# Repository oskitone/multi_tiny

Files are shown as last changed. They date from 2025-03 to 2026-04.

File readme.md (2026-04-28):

# multi_tiny

Thinking about an adapter board to connect multiple ATtiny85s to a single programmer using off-the-shelf DIP parts.

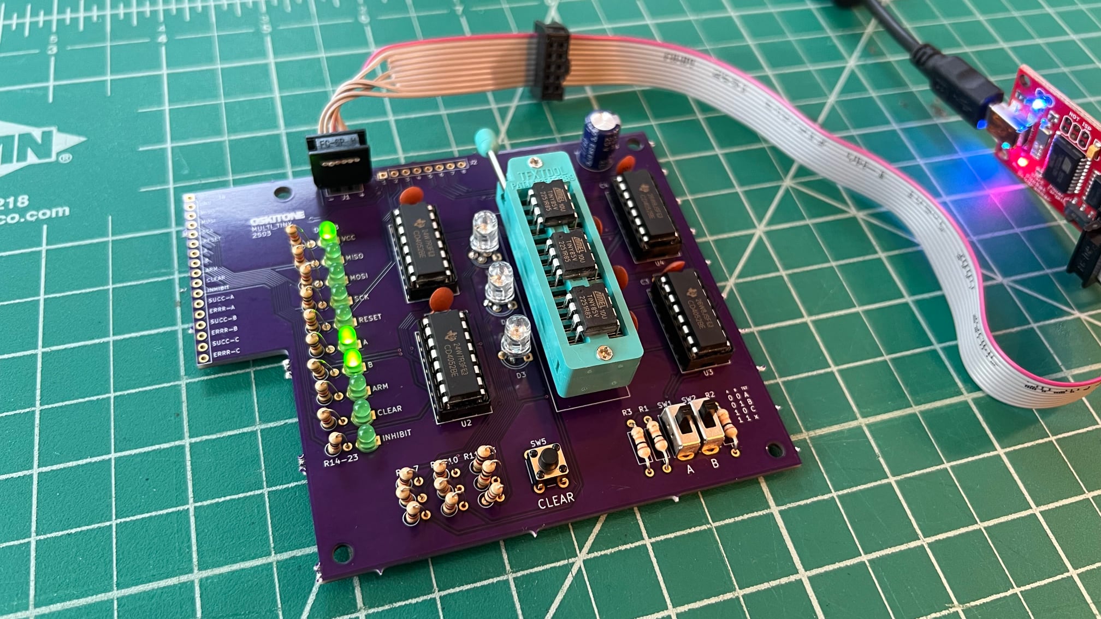
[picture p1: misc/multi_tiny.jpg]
multi_tiny


_Incredibly_ work-in-progress.

## Requirements / Goals

- Long ZIF socket for fast engagement on multiple chips simultaneously
- Programming is done on each chip individually
- Each chip can connect to target PCB for manual testing
- Support for both manual chip and auto/digital chip selection
- Indicators for board/chip-level statuses
- ~Chainable

## PCB TODOs

- Reverse address pin switch order
- Fix ZIF footprint. Component pins are larger than regular DIP socket
- Unused row fixture holes are misplaced
- Maybe rethink IO header position

## Open questions / Down the line / Considerations

- Do I really need four discrete, per-chip pins to program? Sharing common pins and only multiplexing the minimum could simplify BOM.
- Standalone operation w/o a big computer. Raspberry Pi? SD card for storing hex?
- Queue system: load ZIF and mark ready for programming. LEDs indicate when they're ready, and they can be removed while other ZIFs are being used.
- Arbitrary pin routing to support other chips, pin counts, and number of chips per socket
- For now, intentionally not pursuing...
  - Chip switching could be done with manual switches instead of multiplexers. They'd be weird and expensive and obviously not digitally controllable.
  - Programming chips in parallel is feasible (and, anecdotally, commonplace) but require extra verification to test.
  - Could skip multiplexers and instead use multiple sets of GPIO for ICSP pins. It moves a a lot of the complexity into software, which might be nice! Cons: heavily coupled to specific tech, connecting to a target PCB less straightforward.
  - I'm using the 28 pin ZIF because that's what I have for programming the ATmega328. 32 and 40 pin ZIFs have wider pin spacings but, if I'm reading correctly, may still work for DIP8 chipss.

## `DATE REV 2503`

### Schematic

schematic

### BOM

| Designator | Footprint | Quantity | Designation |
| --- | --- | --- | --- |
| C1 to C7 | C_Disc_D5.0mm_W2.5mm_P5.00mm | 7 | .1uF |
| C8 | CP_Radial_D8.0mm_P3.50mm | 1 | 220uF |
| D1 to D3 | LED_D5.0mm-4_RGB_Staggered_Pins | 3 | LED_RKGB |
| D4 to D13  | LED_D3.0mm | 10 | LED |
| J1 | PinHeader_2x03_P2.54mm_Vertical | 1 | Conn_02x03_Odd_Even |
| J2 | PinHeader_1x08_P2.54mm_Vertical | 1 | Conn_01x08 |
| J3 | DIP-28_W7.62mm_LongPads | 1 | 28pin ZIF |
| J4 | PinHeader_1x17_P2.54mm_Vertical | 1 | Conn_01x17 |
| R1 to R3 | R_Axial_DIN0207_L6.3mm_D2.5mm_P10.16mm_Horizontal | 3 | 10k |
| R5 to R23  | R_Axial_DIN0207_L6.3mm_D2.5mm_P2.54mm_Vertical | 19 | 1k |
| SW1, SW2 | SW_Slide_SPDT_Straight_CK_OS102011MS2Q | 2 | SW_SPDT |
| SW4, SW5 | SW_PUSH_6mm | 2 | SW_SPST |
| U1 to U4 | DIP-16_W7.62mm_Socket_LongPads | 4 | CD4052B |

## License

Designed by Oskitone. Please support future projects by purchasing from [Oskitone](https://www.oskitone.com/).

Creative Commons Attribution/Share-Alike, all text above must be included in any redistribution. See license.txt for additional details.

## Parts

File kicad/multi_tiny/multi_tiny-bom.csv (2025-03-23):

Id | Designator | Footprint | Quantity | Designation | Supplier and ref
1 | U4,U2,U1,U3 | DIP-16_W7.62mm_Socket_LongPads | 4 | CD4052B
2 | mouse-bite-1mm-3mm,mouse-bite-1mm-3mm,mouse-bite-1mm-3mm | mouse-bite-1mm-3mm | 3 | VAL**
3 | J1 | PinHeader_2x03_P2.54mm_Vertical | 1 | Conn_02x03_Odd_Even
4 | J3 | DIP-28_W7.62mm_LongPads | 1 | 28pin ZIF
5 | R22,R13,R18,R8,R16,R6,R10,R21,R14,R7,R11,R23,R20,R15,R12,R19,R9,R17,R5 | R_Axial_DIN0207_L6.3mm_D2.5mm_P2.54mm_Vertical | 19 | 1k
6 | D5 | LED_D3.0mm | 1 | MISO
7 | C1,C2,C7,C6,C5,C3,C4 | C_Disc_D5.0mm_W2.5mm_P5.00mm | 7 | .1uF
8 | SW4,SW5 | SW_PUSH_6mm | 2 | SW_SPST
9 | D13 | LED_D3.0mm | 1 | INHIBIT
10 | R3,R2,R1 | R_Axial_DIN0207_L6.3mm_D2.5mm_P10.16mm_Horizontal | 3 | 10k
11 | Ref**,Ref** | branding | 2 | Val**
12 | D9 | LED_D3.0mm | 1 | A
13 | D12 | LED_D3.0mm | 1 | CLEAR
14 | D6 | LED_D3.0mm | 1 | MOSI
15 | J2 | PinHeader_1x08_P2.54mm_Vertical | 1 | Conn_01x08
16 | J4 | PinHeader_1x17_P2.54mm_Vertical | 1 | Conn_01x17
17 | D1,D3,D2 | LED_D5.0mm-4_RGB_Staggered_Pins | 3 | LED_RKGB
18 | SW1,SW2 | SW_Slide_SPDT_Straight_CK_OS102011MS2Q | 2 | SW_SPDT
19 | D4 | LED_D3.0mm | 1 | VCC
20 | D8 | LED_D3.0mm | 1 | RESET
21 | C8 | CP_Radial_D8.0mm_P3.50mm | 1 | 220uF
22 | D7 | LED_D3.0mm | 1 | SCK
23 | D10 | LED_D3.0mm | 1 | B
24 | D11 | LED_D3.0mm | 1 | ARM

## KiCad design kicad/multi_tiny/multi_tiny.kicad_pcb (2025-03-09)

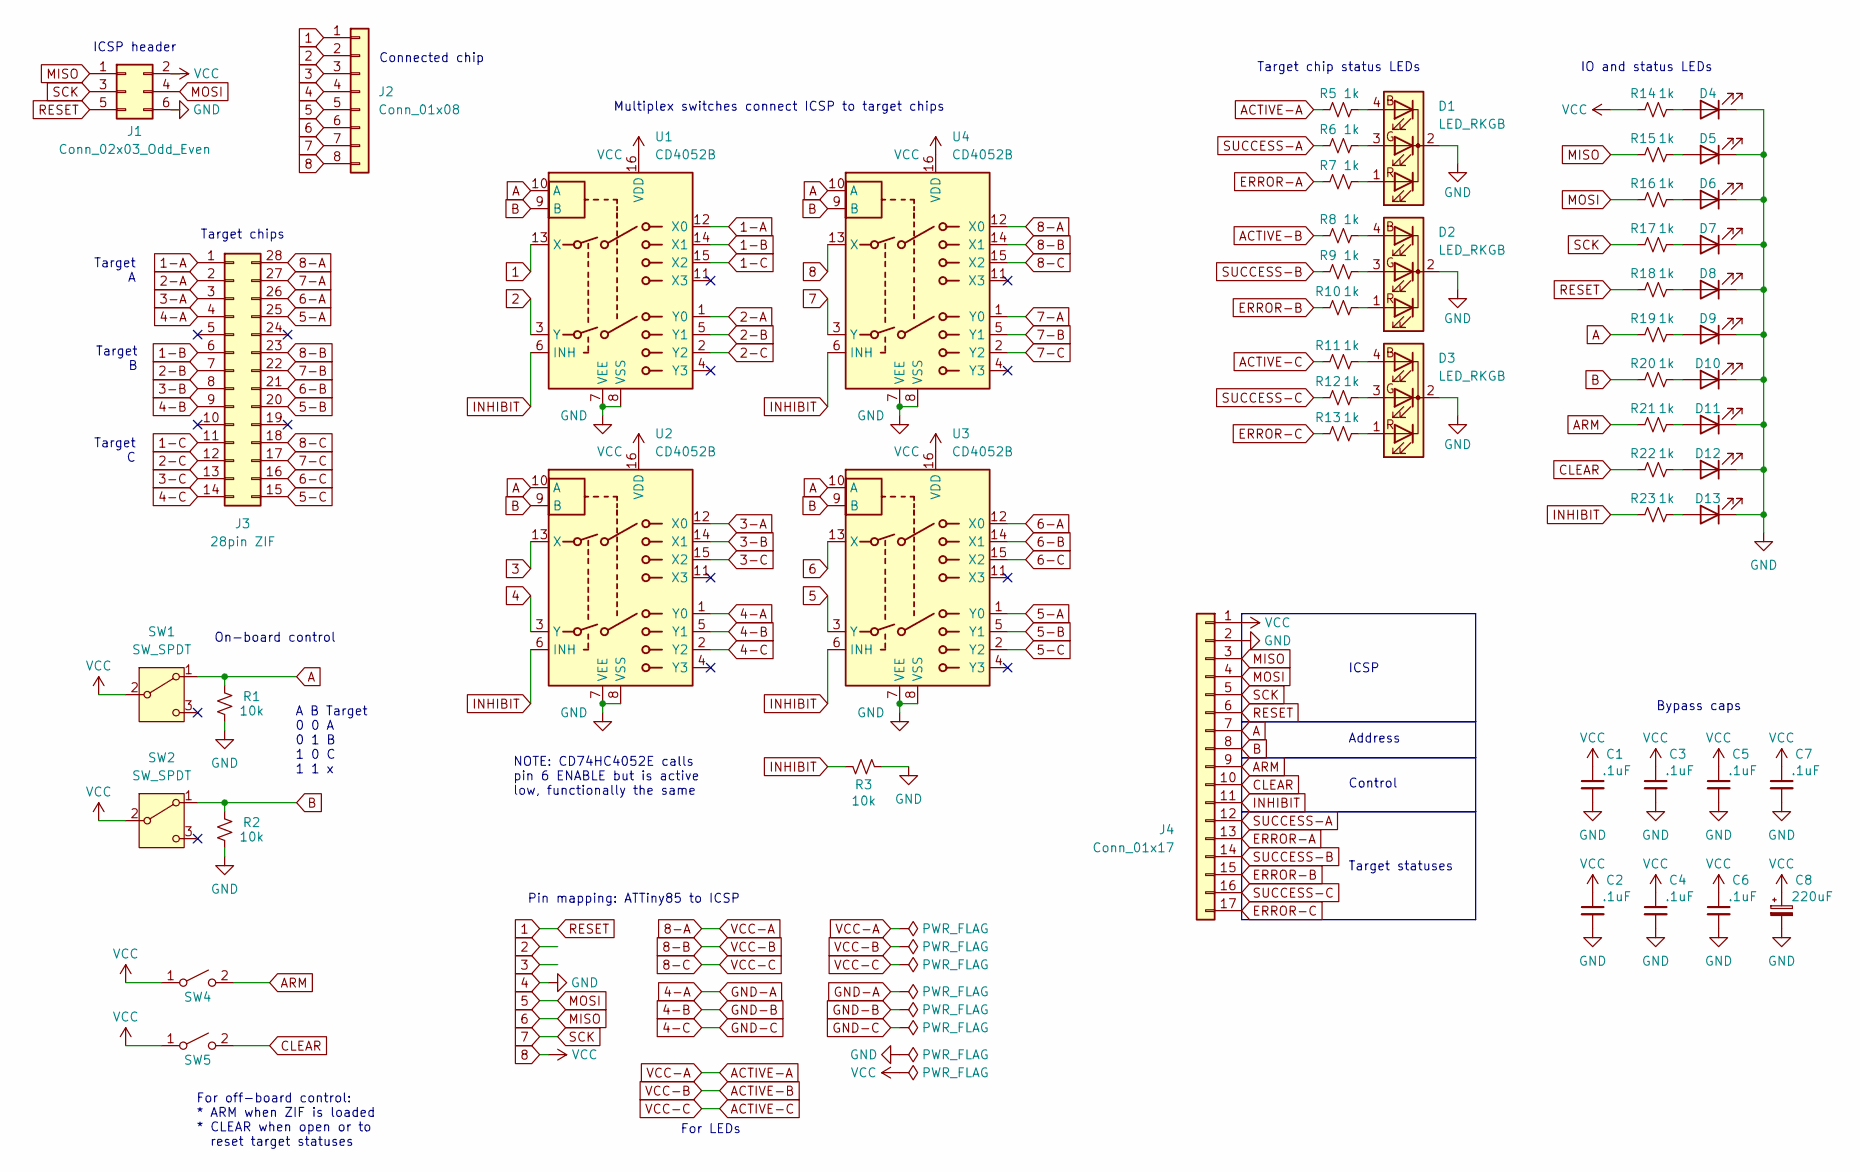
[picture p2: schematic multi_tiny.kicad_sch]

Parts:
C1, C2, C3, C4, C5, C6, C7: .1uF; C_Disc_D5.0mm_W2.5mm_P5.00mm
C8: 220uF; CP_Radial_D8.0mm_P3.50mm
D1, D2, D3: LED_RKGB; LED_D5.0mm-4_RGB_Staggered_Pins
D4: VCC; LED_D3.0mm
D5: MISO; LED_D3.0mm
D6: MOSI; LED_D3.0mm
D7: SCK; LED_D3.0mm
D8: RESET; LED_D3.0mm
D9: A; LED_D3.0mm
D10: B; LED_D3.0mm
D11: ARM; LED_D3.0mm
D12: CLEAR; LED_D3.0mm
D13: INHIBIT; LED_D3.0mm
J1: Conn_02x03_Odd_Even; PinHeader_2x03_P2.54mm_Vertical
J2: Conn_01x08; PinHeader_1x08_P2.54mm_Vertical
J3: 28pin ZIF; DIP-28_W7.62mm_LongPads
J4: Conn_01x17; PinHeader_1x17_P2.54mm_Vertical
R1, R2, R3: 10k; R_Axial_DIN0207_L6.3mm_D2.5mm_P10.16mm_Horizontal
R5, R6, R7, R8, R9, R10, R11, R12, R13, R14, R15, R16, R17, R18, R19, R20, R21, R22, R23: 1k; R_Axial_DIN0207_L6.3mm_D2.5mm_P2.54mm_Vertical
SW1, SW2: SW_SPDT; SW_Slide_SPDT_Straight_CK_OS102011MS2Q
SW4, SW5: SW_SPST; SW_PUSH_6mm
U1, U2, U3, U4: CD4052B; DIP-16_W7.62mm_Socket_LongPads

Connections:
1: J1.5, J2.1, J4.6, R18.1, U1.13 (X)
1-A: J3.1, U1.12 (X0)
1-B: J3.6, U1.14 (X1)
1-C: J3.11, U1.15 (X2)
2: J2.2, U1.3 (Y)
2-A: J3.2, U1.1 (Y0)
2-B: J3.7, U1.5 (Y1)
2-C: J3.12, U1.2 (Y2)
3: J2.3, U2.13 (X)
3-A: J3.3, U2.12 (X0)
3-B: J3.8, U2.14 (X1)
3-C: J3.13, U2.15 (X2)
4: C1.2, C2.2, C3.2, C4.2, C5.2, C6.2, C7.2, C8.2, D1.2 (K), D2.2 (K), D3.2 (K), D4.1 (K), D5.1 (K), D6.1 (K), D7.1 (K), D8.1 (K), D9.1 (K), D10.1 (K), D11.1 (K), D12.1 (K), D13.1 (K), J1.6, J2.4, J4.2, R1.1, R2.1, R3.1, U1.7 (VEE), U1.8 (VSS), U2.3 (Y), U2.7 (VEE), U2.8 (VSS), U3.7 (VEE), U3.8 (VSS), U4.7 (VEE), U4.8 (VSS)
4-A: J3.4, U2.1 (Y0)
4-B: J3.9, U2.5 (Y1)
4-C: J3.14, U2.2 (Y2)
5: J1.4, J2.5, J4.4, R16.1, U3.3 (Y)
5-A: J3.25, U3.1 (Y0)
5-B: J3.20, U3.5 (Y1)
5-C: J3.15, U3.2 (Y2)
6: J1.1, J2.6, J4.3, R15.1, U3.13 (X)
6-A: J3.26, U3.12 (X0)
6-B: J3.21, U3.14 (X1)
6-C: J3.16, U3.15 (X2)
7: J1.3, J2.7, J4.5, R17.1, U4.3 (Y)
7-A: J3.27, U4.1 (Y0)
7-B: J3.22, U4.5 (Y1)
7-C: J3.17, U4.2 (Y2)
8: C1.1, C2.1, C3.1, C4.1, C5.1, C6.1, C7.1, C8.1, J1.2, J2.8, J4.1, R14.1, SW1.2 (B), SW2.2 (B), SW4.1 (A), SW5.1 (A), U1.16 (VDD), U2.16 (VDD), U3.16 (VDD), U4.13 (X), U4.16 (VDD)
8-A: J3.28, R5.1, U4.12 (X0)
8-B: J3.23, R8.1, U4.14 (X1)
8-C: J3.18, R11.1, U4.15 (X2)
A: J4.7, R1.2, R19.1, SW1.1 (A), U1.10 (A), U2.10 (A), U3.10 (A), U4.10 (A)
ARM: J4.9, R21.1, SW4.2 (B)
B: J4.8, R2.2, R20.1, SW2.1 (A), U1.9 (B), U2.9 (B), U3.9 (B), U4.9 (B)
CLEAR: J4.10, R22.1, SW5.2 (B)
ERROR-A: J4.13, R7.1
ERROR-B: J4.15, R10.1
ERROR-C: J4.17, R13.1
INHIBIT: J4.11, R3.2, R23.1, U1.6 (INH), U2.6 (INH), U3.6 (INH), U4.6 (INH)
unnamed: D1.4 (BA), R5.2
unnamed: D1.3 (GA), R6.2
unnamed: D1.1 (RA), R7.2
unnamed: D2.4 (BA), R8.2
unnamed: D2.3 (GA), R9.2
unnamed: D2.1 (RA), R10.2
unnamed: D3.4 (BA), R11.2
unnamed: D3.3 (GA), R12.2
unnamed: D3.1 (RA), R13.2
unnamed: D4.2 (A), R14.2
unnamed: D5.2 (A), R15.2
unnamed: D6.2 (A), R16.2
unnamed: D7.2 (A), R17.2
unnamed: D8.2 (A), R18.2
unnamed: D9.2 (A), R19.2
unnamed: D10.2 (A), R20.2
unnamed: D11.2 (A), R21.2
unnamed: D12.2 (A), R22.2
unnamed: D13.2 (A), R23.2
SUCCESS-A: J4.12, R6.1
SUCCESS-B: J4.14, R9.1
SUCCESS-C: J4.16, R12.1

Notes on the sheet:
Target C
Control
A B Target 0 0 A 0 1 B 1 0 C 1 1 x
Target chips
For off-board control: * ARM when ZIF is loaded * CLEAR when open or to reset target statuses
Connected chip
Address
Pin mapping: ATTiny85 to ICSP
Multiplex switches connect ICSP to target chips
ICSP
IO and status LEDs
Bypass caps
Target chip status LEDs
Target B
ICSP header
NOTE: CD74HC4052E calls pin 6 ENABLE but is active low, functionally the same
Target A
For LEDs
On-board control
Target statuses

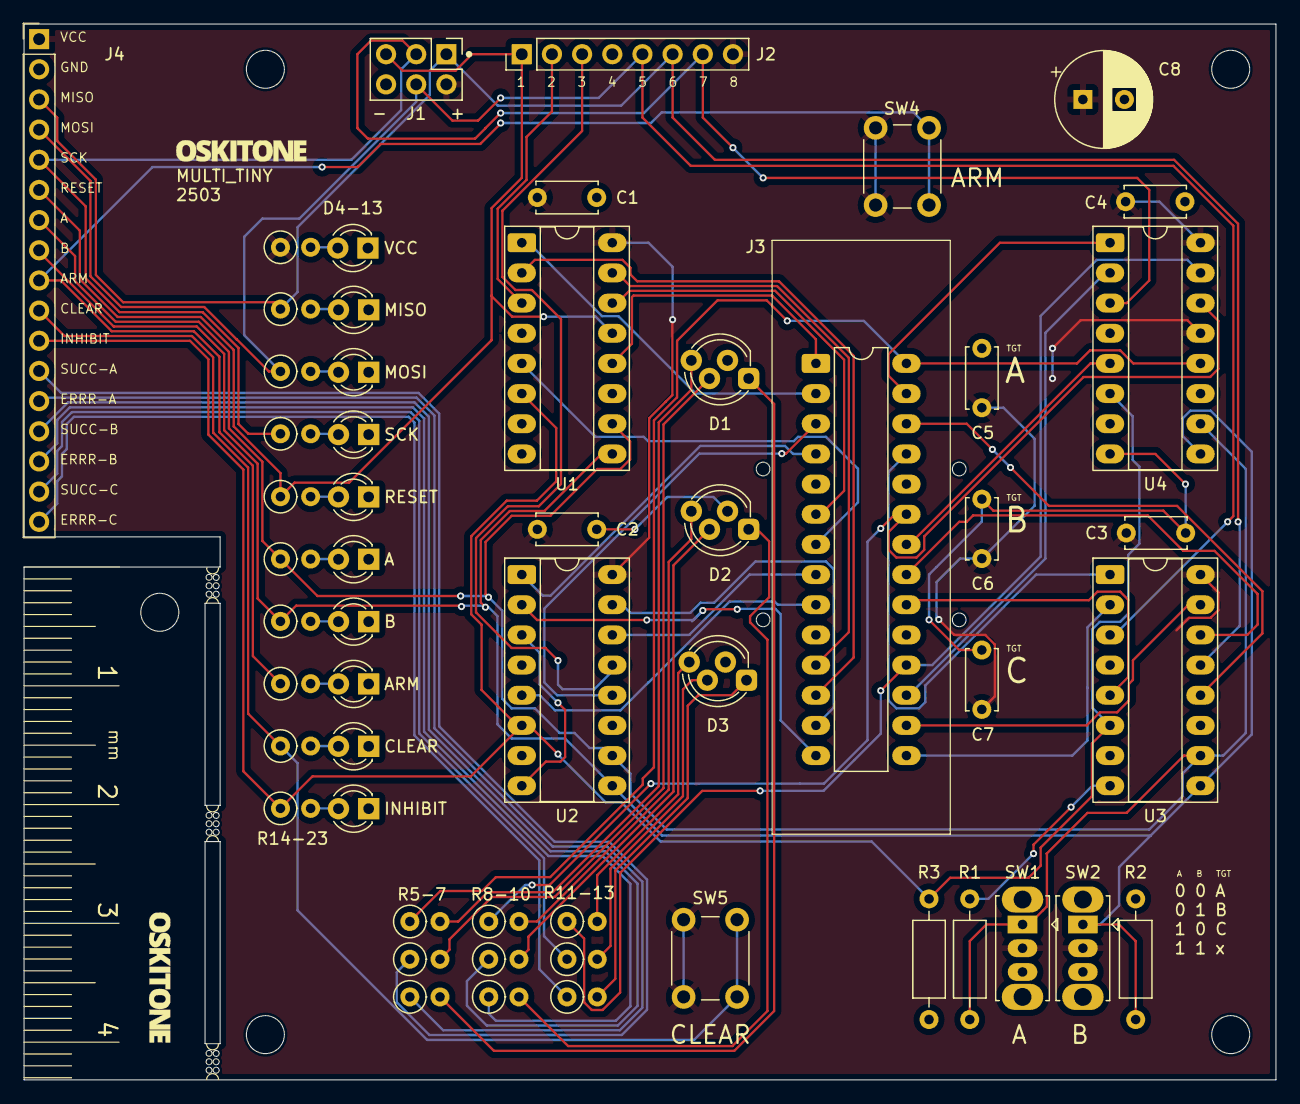
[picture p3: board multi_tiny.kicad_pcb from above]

Board: 2 copper layers, 105.4 x 88.9 mm, 60 parts (0 on the bottom side), 62 nets.

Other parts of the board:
Ref**: Val**; branding
Ref**#2: Val**; branding
mouse-bite-1mm-3mm, mouse-bite-1mm-3mm#2, mouse-bite-1mm-3mm#3: VAL**; mouse-bite-1mm-3mm

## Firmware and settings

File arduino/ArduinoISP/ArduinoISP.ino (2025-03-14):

// ArduinoISP
// Copyright (c) 2008-2011 Randall Bohn
// If you require a license, see
// https://opensource.org/licenses/bsd-license.php
//
// This sketch turns the Arduino into a AVRISP using the following Arduino pins:
//
// Pin 10 is used to reset the target microcontroller.
//
// By default, the hardware SPI pins MISO, MOSI and SCK are used to communicate
// with the target. On all Arduinos, these pins can be found
// on the ICSP/SPI header:
//
//               MISO °. . 5V (!) Avoid this pin on Due, Zero...
//               SCK   . . MOSI
//                     . . GND
//
// On some Arduinos (Uno,...), pins MOSI, MISO and SCK are the same pins as
// digital pin 11, 12 and 13, respectively. That is why many tutorials instruct
// you to hook up the target to these pins. If you find this wiring more
// practical, have a define USE_OLD_STYLE_WIRING. This will work even when not
// using an Uno. (On an Uno this is not needed).
//
// Alternatively you can use any other digital pin by configuring
// software ('BitBanged') SPI and having appropriate defines for
// ARDUINOISP_PIN_MOSI, ARDUINOISP_PIN_MISO and ARDUINOISP_PIN_SCK.
//
// IMPORTANT: When using an Arduino that is not 5V tolerant (Due, Zero, ...) as
// the programmer, make sure to not expose any of the programmer's pins to 5V.
// A simple way to accomplish this is to power the complete system (programmer
// and target) at 3V3.
//
// Put an LED (with resistor) on the following pins:
// 9: Heartbeat   - shows the programmer is running
// 8: Error       - Lights up if something goes wrong (use red if that makes
// sense) 7: Programming - In communication with the target
//

#include "Arduino.h"
#undef SERIAL

#define PROG_FLICKER true

// Configure SPI clock (in Hz).
// E.g. for an ATtiny @ 128 kHz: the datasheet states that both the high and low
// SPI clock pulse must be > 2 CPU cycles, so take 3 cycles i.e. divide target
// f_cpu by 6:
//     #define SPI_CLOCK            (128000/6)
//
// A clock slow enough for an ATtiny85 @ 1 MHz, is a reasonable default:

#define SPI_CLOCK (1000000 / 6)

// Select hardware or software SPI, depending on SPI clock.
// Currently only for AVR, for other architectures (Due, Zero,...), hardware SPI
// is probably too fast anyway.

#if defined(ARDUINO_ARCH_AVR)

#if SPI_CLOCK > (F_CPU / 128)
#define USE_HARDWARE_SPI
#endif

#endif

// Configure which pins to use:

// The standard pin configuration.
#ifndef ARDUINO_HOODLOADER2

#define RESET 10 // Use pin 10 to reset the target rather than SS
#define LED_HB 9
#define LED_ERR 8
#define LED_PMODE 7

// Uncomment following line to use the old Uno style wiring
// (using pin 11, 12 and 13 instead of the SPI header) on Leonardo, Due...

// #define USE_OLD_STYLE_WIRING

#ifdef USE_OLD_STYLE_WIRING

#define ARDUINOISP_PIN_MOSI 11
#define ARDUINOISP_PIN_MISO 12
#define ARDUINOISP_PIN_SCK 13

#endif

// HOODLOADER2 means running sketches on the ATmega16U2 serial converter chips
// on Uno or Mega boards. We must use pins that are broken out:
#else

#define RESET 4
#define LED_HB 7
#define LED_ERR 6
#define LED_PMODE 5

#endif

// By default, use hardware SPI pins:
#ifndef ARDUINOISP_PIN_MOSI
#define ARDUINOISP_PIN_MOSI MOSI
#endif

#ifndef ARDUINOISP_PIN_MISO
#define ARDUINOISP_PIN_MISO MISO
#endif

#ifndef ARDUINOISP_PIN_SCK
#define ARDUINOISP_PIN_SCK SCK
#endif

// Force bitbanged SPI if not using the hardware SPI pins:
#if (ARDUINOISP_PIN_MISO != MISO) || (ARDUINOISP_PIN_MOSI != MOSI) ||          \
    (ARDUINOISP_PIN_SCK != SCK)
#undef USE_HARDWARE_SPI
#endif

// Configure the serial port to use.
//
// Prefer the USB virtual serial port (aka. native USB port), if the Arduino has
// one:
//   - it does not autoreset (except for the magic baud rate of 1200).
//   - it is more reliable because of USB handshaking.
//
// Leonardo and similar have an USB virtual serial port: 'Serial'.
// Due and Zero have an USB virtual serial port: 'SerialUSB'.
//
// On the Due and Zero, 'Serial' can be used too, provided you disable
// autoreset. To use 'Serial': #define SERIAL Serial

#ifdef SERIAL_PORT_USBVIRTUAL
#define SERIAL SERIAL_PORT_USBVIRTUAL
#else
#define SERIAL Serial
#endif

// Configure the baud rate:

#define BAUDRATE 19200
// #define BAUDRATE	115200
// #define BAUDRATE	1000000

#define HWVER 2
#define SWMAJ 1
#define SWMIN 18

// STK Definitions
#define STK_OK 0x10
#define STK_FAILED 0x11
#define STK_UNKNOWN 0x12
#define STK_INSYNC 0x14
#define STK_NOSYNC 0x15
#define CRC_EOP 0x20 // ok it is a space...

void pulse(int pin, int times);

#ifdef USE_HARDWARE_SPI
#include "SPI.h"
#else

#define SPI_MODE0 0x00

#if !defined(ARDUINO_API_VERSION) ||                                           \
    ARDUINO_API_VERSION !=                                                     \
        10001 // A SPISettings class is declared by ArduinoCore-API 1.0.1
class SPISettings {
public:
  // clock is in Hz
  SPISettings(uint32_t clock, uint8_t bitOrder, uint8_t dataMode)
      : clockFreq(clock) {
    (void)bitOrder;
    (void)dataMode;
  };

  uint32_t getClockFreq() const { return clockFreq; }

private:
  uint32_t clockFreq;
};
#endif        // !defined(ARDUINO_API_VERSION)

class BitBangedSPI {
public:
  void begin() {
    digitalWrite(ARDUINOISP_PIN_SCK, LOW);
    digitalWrite(ARDUINOISP_PIN_MOSI, LOW);
    pinMode(ARDUINOISP_PIN_SCK, OUTPUT);
    pinMode(ARDUINOISP_PIN_MOSI, OUTPUT);
    pinMode(ARDUINOISP_PIN_MISO, INPUT);
  }

  void beginTransaction(SPISettings settings) {
    pulseWidth =
        (500000 + settings.getClockFreq() - 1) / settings.getClockFreq();
    if (pulseWidth == 0) {
      pulseWidth = 1;
    }
  }

  void end() {}

  uint8_t transfer(uint8_t b) {
    for (unsigned int i = 0; i < 8; ++i) {
      digitalWrite(ARDUINOISP_PIN_MOSI, (b & 0x80) ? HIGH : LOW);
      digitalWrite(ARDUINOISP_PIN_SCK, HIGH);
      delayMicroseconds(pulseWidth);
      b = (b << 1) | digitalRead(ARDUINOISP_PIN_MISO);
      digitalWrite(ARDUINOISP_PIN_SCK, LOW); // slow pulse
      delayMicroseconds(pulseWidth);
    }
    return b;
  }

private:
  unsigned long pulseWidth; // in microseconds
};

static BitBangedSPI SPI;

#endif

void setup() {
  SERIAL.begin(BAUDRATE);

  pinMode(LED_PMODE, OUTPUT);
  pulse(LED_PMODE, 2);
  pinMode(LED_ERR, OUTPUT);
  pulse(LED_ERR, 2);
  pinMode(LED_HB, OUTPUT);
  pulse(LED_HB, 2);
}

int ISPError = 0;
int pmode = 0;
// address for reading and writing, set by 'U' command
unsigned int here;
uint8_t buff[256]; // global block storage

#define beget16(addr) (*addr * 256 + *(addr + 1))
typedef struct param {
  uint8_t devicecode;
  uint8_t revision;
  uint8_t progtype;
  uint8_t parmode;
  uint8_t polling;
  uint8_t selftimed;
  uint8_t lockbytes;
  uint8_t fusebytes;
  uint8_t flashpoll;
  uint16_t eeprompoll;
  uint16_t pagesize;
  uint16_t eepromsize;
  uint32_t flashsize;
} parameter;

parameter param;

// this provides a heartbeat on pin 9, so you can tell the software is running.
uint8_t hbval = 128;
int8_t hbdelta = 8;
void heartbeat() {
  static unsigned long last_time = 0;
  unsigned long now = millis();
  if ((now - last_time) < 40) {
    return;
  }
  last_time = now;
  if (hbval > 192) {
    hbdelta = -hbdelta;
  }
  if (hbval < 32) {
    hbdelta = -hbdelta;
  }
  hbval += hbdelta;
  analogWrite(LED_HB, hbval);
}

static bool rst_active_high;

void reset_target(bool reset) {
  digitalWrite(RESET,
               ((reset && rst_active_high) || (!reset && !rst_active_high))
                   ? HIGH
                   : LOW);
}

void loop(void) {
  // is pmode active?
  if (pmode) {
    digitalWrite(LED_PMODE, HIGH);
  } else {
    digitalWrite(LED_PMODE, LOW);
  }
  // is there an error?
  if (ISPError) {
    digitalWrite(LED_ERR, HIGH);
  } else {
    digitalWrite(LED_ERR, LOW);
  }

  // light the heartbeat LED
  heartbeat();
  if (SERIAL.available()) {
    avrisp();
  }
}

uint8_t getch() {
  while (!SERIAL.available())
    ;
  return SERIAL.read();
}
void fill(int n) {
  for (int x = 0; x < n; x++) {
    buff[x] = getch();
  }
}

#define PTIME 30
void pulse(int pin, int times) {
  do {
    digitalWrite(pin, HIGH);
    delay(PTIME);
    digitalWrite(pin, LOW);
    delay(PTIME);
  } while (times--);
}

void prog_lamp(int state) {
  if (PROG_FLICKER) {
    digitalWrite(LED_PMODE, state);
  }
}

uint8_t spi_transaction(uint8_t a, uint8_t b, uint8_t c, uint8_t d) {
  SPI.transfer(a);
  SPI.transfer(b);
  SPI.transfer(c);
  return SPI.transfer(d);
}

void empty_reply() {
  if (CRC_EOP == getch()) {
    SERIAL.print((char)STK_INSYNC);
    SERIAL.print((char)STK_OK);
  } else {
    ISPError++;
    SERIAL.print((char)STK_NOSYNC);
  }
}

void breply(uint8_t b) {
  if (CRC_EOP == getch()) {
    SERIAL.print((char)STK_INSYNC);
    SERIAL.print((char)b);
    SERIAL.print((char)STK_OK);
  } else {
    ISPError++;
    SERIAL.print((char)STK_NOSYNC);
  }
}

void get_version(uint8_t c) {
  switch (c) {
  case 0x80:
    breply(HWVER);
    break;
  case 0x81:
    breply(SWMAJ);
    break;
  case 0x82:
    breply(SWMIN);
    break;
  case 0x93:
    breply('S'); // serial programmer
    break;
  default:
    breply(0);
  }
}

void set_parameters() {
  // call this after reading parameter packet into buff[]
  param.devicecode = buff[0];
  param.revision = buff[1];
  param.progtype = buff[2];
  param.parmode = buff[3];
  param.polling = buff[4];
  param.selftimed = buff[5];
  param.lockbytes = buff[6];
  param.fusebytes = buff[7];
  param.flashpoll = buff[8];
  // ignore buff[9] (= buff[8])
  // following are 16 bits (big endian)
  param.eeprompoll = beget16(&buff[10]);
  param.pagesize = beget16(&buff[12]);
  param.eepromsize = beget16(&buff[14]);

  // 32 bits flashsize (big endian)
  param.flashsize = buff[16] * 0x01000000 + buff[17] * 0x00010000 +
                    buff[18] * 0x00000100 + buff[19];

  // AVR devices have active low reset, AT89Sx are active high
  rst_active_high = (param.devicecode >= 0xe0);
}

void start_pmode() {

  // Reset target before driving ARDUINOISP_PIN_SCK or ARDUINOISP_PIN_MOSI

  // SPI.begin() will configure SS as output, so SPI master mode is selected.
  // We have defined RESET as pin 10, which for many Arduinos is not the SS pin.
  // So we have to configure RESET as output here,
  // (reset_target() first sets the correct level)
  reset_target(true);
  pinMode(RESET, OUTPUT);
  SPI.begin();
  SPI.beginTransaction(SPISettings(SPI_CLOCK, MSBFIRST, SPI_MODE0));

  // See AVR datasheets, chapter "SERIAL_PRG Programming Algorithm":

  // Pulse RESET after ARDUINOISP_PIN_SCK is low:
  digitalWrite(ARDUINOISP_PIN_SCK, LOW);
  delay(20); // discharge ARDUINOISP_PIN_SCK, value arbitrarily chosen
  reset_target(false);
  // Pulse must be minimum 2 target CPU clock cycles so 100 usec is ok for CPU
  // speeds above 20 KHz
  delayMicroseconds(100);
  reset_target(true);

  // Send the enable programming command:
  delay(50); // datasheet: must be > 20 msec
  spi_transaction(0xAC, 0x53, 0x00, 0x00);
  pmode = 1;
}

void end_pmode() {
  SPI.end();
  // We're about to take the target out of reset so configure SPI pins as input
  pinMode(ARDUINOISP_PIN_MOSI, INPUT);
  pinMode(ARDUINOISP_PIN_SCK, INPUT);
  reset_target(false);
  pinMode(RESET, INPUT);
  pmode = 0;
}

void universal() {
  uint8_t ch;

  fill(4);
  ch = spi_transaction(buff[0], buff[1], buff[2], buff[3]);
  breply(ch);
}

void flash(uint8_t hilo, unsigned int addr, uint8_t data) {
  spi_transaction(0x40 + 8 * hilo, addr >> 8 & 0xFF, addr & 0xFF, data);
}
void commit(unsigned int addr) {
  if (PROG_FLICKER) {
    prog_lamp(LOW);
  }
  spi_transaction(0x4C, (addr >> 8) & 0xFF, addr & 0xFF, 0);
  if (PROG_FLICKER) {
    delay(PTIME);
    prog_lamp(HIGH);
  }
}

unsigned int current_page() {
  if (param.pagesize == 32) {
    return here & 0xFFFFFFF0;
  }
  if (param.pagesize == 64) {
    return here & 0xFFFFFFE0;
  }
  if (param.pagesize == 128) {
    return here & 0xFFFFFFC0;
  }
  if (param.pagesize == 256) {
    return here & 0xFFFFFF80;
  }
  return here;
}

void write_flash(int length) {
  fill(length);
  if (CRC_EOP == getch()) {
    SERIAL.print((char)STK_INSYNC);
    SERIAL.print((char)write_flash_pages(length));
  } else {
    ISPError++;
    SERIAL.print((char)STK_NOSYNC);
  }
}

uint8_t write_flash_pages(int length) {
  int x = 0;
  unsigned int page = current_page();
  while (x < length) {
    if (page != current_page()) {
      commit(page);
      page = current_page();
    }
    flash(LOW, here, buff[x++]);
    flash(HIGH, here, buff[x++]);
    here++;
  }

  commit(page);

  return STK_OK;
}

#define EECHUNK (32)
uint8_t write_eeprom(unsigned int length) {
  // here is a word address, get the byte address
  unsigned int start = here * 2;
  unsigned int remaining = length;
  if (length > param.eepromsize) {
    ISPError++;
    return STK_FAILED;
  }
  while (remaining > EECHUNK) {
    write_eeprom_chunk(start, EECHUNK);
    start += EECHUNK;
    remaining -= EECHUNK;
  }
  write_eeprom_chunk(start, remaining);
  return STK_OK;
}
// write (length) bytes, (start) is a byte address
uint8_t write_eeprom_chunk(unsigned int start, unsigned int length) {
  // this writes byte-by-byte, page writing may be faster (4 bytes at a time)
  fill(length);
  prog_lamp(LOW);
  for (unsigned int x = 0; x < length; x++) {
    unsigned int addr = start + x;
    spi_transaction(0xC0, (addr >> 8) & 0xFF, addr & 0xFF, buff[x]);
    delay(45);
  }
  prog_lamp(HIGH);
  return STK_OK;
}

void program_page() {
  char result = (char)STK_FAILED;
  unsigned int length = 256 * getch();
  length += getch();
  char memtype = getch();
  // flash memory @here, (length) bytes
  if (memtype == 'F') {
    write_flash(length);
    return;
  }
  if (memtype == 'E') {
    result = (char)write_eeprom(length);
    if (CRC_EOP == getch()) {
      SERIAL.print((char)STK_INSYNC);
      SERIAL.print(result);
    } else {
      ISPError++;
      SERIAL.print((char)STK_NOSYNC);
    }
    return;
  }
  SERIAL.print((char)STK_FAILED);
  return;
}

uint8_t flash_read(uint8_t hilo, unsigned int addr) {
  return spi_transaction(0x20 + hilo * 8, (addr >> 8) & 0xFF, addr & 0xFF, 0);
}

char flash_read_page(int length) {
  for (int x = 0; x < length; x += 2) {
    uint8_t low = flash_read(LOW, here);
    SERIAL.print((char)low);
    uint8_t high = flash_read(HIGH, here);
    SERIAL.print((char)high);
    here++;
  }
  return STK_OK;
}

char eeprom_read_page(int length) {
  // here again we have a word address
  int start = here * 2;
  for (int x = 0; x < length; x++) {
    int addr = start + x;
    uint8_t ee = spi_transaction(0xA0, (addr >> 8) & 0xFF, addr & 0xFF, 0xFF);
    SERIAL.print((char)ee);
  }
  return STK_OK;
}

void read_page() {
  char result = (char)STK_FAILED;
  int length = 256 * getch();
  length += getch();
  char memtype = getch();
  if (CRC_EOP != getch()) {
    ISPError++;
    SERIAL.print((char)STK_NOSYNC);
    return;
  }
  SERIAL.print((char)STK_INSYNC);
  if (memtype == 'F') {
    result = flash_read_page(length);
  }
  if (memtype == 'E') {
    result = eeprom_read_page(length);
  }
  SERIAL.print(result);
}

void read_signature() {
  if (CRC_EOP != getch()) {
    ISPError++;
    SERIAL.print((char)STK_NOSYNC);
    return;
  }
  SERIAL.print((char)STK_INSYNC);
  uint8_t high = spi_transaction(0x30, 0x00, 0x00, 0x00);
  SERIAL.print((char)high);
  uint8_t middle = spi_transaction(0x30, 0x00, 0x01, 0x00);
  SERIAL.print((char)middle);
  uint8_t low = spi_transaction(0x30, 0x00, 0x02, 0x00);
  SERIAL.print((char)low);
  SERIAL.print((char)STK_OK);
}
//////////////////////////////////////////
//////////////////////////////////////////

////////////////////////////////////
////////////////////////////////////
void avrisp() {
  uint8_t ch = getch();
  switch (ch) {
  case '0': // signon
    ISPError = 0;
    empty_reply();
    break;
  case '1':
    if (getch() == CRC_EOP) {
      SERIAL.print((char)STK_INSYNC);
      SERIAL.print("AVR ISP");
      SERIAL.print((char)STK_OK);
    } else {
      ISPError++;
      SERIAL.print((char)STK_NOSYNC);
    }
    break;
  case 'A':
    get_version(getch());
    break;
  case 'B':
    fill(20);
    set_parameters();
    empty_reply();
    break;
  case 'E': // extended parameters - ignore for now
    fill(5);
    empty_reply();
    break;
  case 'P':
    if (!pmode) {
      start_pmode();
    }
    empty_reply();
    break;
  case 'U': // set address (word)
    here = getch();
    here += 256 * getch();
    empty_reply();
    break;

  case 0x60: // STK_PROG_FLASH
    getch(); // low addr
    getch(); // high addr
    empty_reply();
    break;
  case 0x61: // STK_PROG_DATA
    getch(); // data
    empty_reply();
    break;

  case 0x64: // STK_PROG_PAGE
    program_page();
    break;

  case 0x74: // STK_READ_PAGE 't'
    read_page();
    break;

  case 'V': // 0x56
    universal();
    break;
  case 'Q': // 0x51
    ISPError = 0;
    end_pmode();
    empty_reply();
    break;

  case 0x75: // STK_READ_SIGN 'u'
    read_signature();
    break;

  // expecting a command, not CRC_EOP
  // this is how we can get back in sync
  case CRC_EOP:
    ISPError++;
    SERIAL.print((char)STK_NOSYNC);
    break;

  // anything else we will return STK_UNKNOWN
  default:
    ISPError++;
    if (CRC_EOP == getch()) {
      SERIAL.print((char)STK_UNKNOWN);
    } else {
      SERIAL.print((char)STK_NOSYNC);
    }
  }
}

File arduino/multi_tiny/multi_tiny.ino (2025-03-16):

#include "ArduinoISP.h"

void setup() {
  setupArduinoISP();

  // TODO:
  // * 2 for address: AB
  // * 3 for control: ARM, CLEAR, INHIBIT
  // * 6 for target statuses: SUCCESS/ERROR-A/B/C
}

void loop() {
  loopArduinoISP();

  // TODO:
  // * can ArduinoISP loop? might be better for it to be "dumb"
  //   and have logic on host computer?
}

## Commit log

2025-02-22 Start schematic
    [multi_tiny.kicad_pcb, multi_tiny.kicad_sch]
2025-03-01 Complete MVP schematic
    [multi_tiny.kicad_sch]
2025-03-02 Swap CD4051 for another CD4052
    * Simplifies BOM
    * Enables arbitrary pin routing later
    [multi_tiny.kicad_sch]
2025-03-02 Swap chips for ZIF
    [multi_tiny.kicad_sch]
2025-03-03 Add more IO and organize
    [multi_tiny.kicad_sch]
2025-03-04 Finalize schematic to start PCB layout
    For now!
    * Merge DIP8 socket into IO header
    * Add "power" LED
    * Rearrange some stuff
    * Assign footprints
    [multi_tiny.kicad_sch]
2025-03-06 Stub PCB layout
    Schematic changes are mostly for real estate:
    * Combine headers
    * Vertical resistors
    [multi_tiny.kicad_pcb, multi_tiny.kicad_sch]
2025-03-07 Re-layout for flanked ZIF
    [multi_tiny.kicad_pcb, multi_tiny.kicad_sch]
2025-03-08 Re-layout
    * Fix ZIF dimensions
    * IO refinements: ditch inhibit switch, pullups
    on external controls, add clear button
    [multi_tiny.kicad_pcb, multi_tiny.kicad_sch]
2025-03-09 Square PCB
    and put a lil breakaway ruler in the cutout
    [multi_tiny.kicad_pcb]
2025-03-09 Route PCB
    And fix CD4052/target pins arrangement
    [multi_tiny.kicad_pcb, multi_tiny.kicad_sch]
2025-03-09 Obviate/ignore DRC warnings
    [multi_tiny.kicad_pcb, multi_tiny.kicad_sch]
2025-03-14 Save ArduinoISP example script
2025-03-16 Extract ArduinoISP
2025-03-23 Add BOM CSV
    [multi_tiny-bom.csv]
2026-04-28 Update readme after soldering first PCB rev
    * Add a quick photo
    * Doc TODOs
    A promising start
